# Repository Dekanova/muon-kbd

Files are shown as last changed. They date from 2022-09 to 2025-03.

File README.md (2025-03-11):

# A smol and simple osu keypad

This is the Muon PCB.

## Details
Firmware for this board can be found here https://github.com/Dekanova/muon-firmware.
ROM flash is pretty big and should be able to fit whatever you want on it.

Feel free to make a PR if you get other firmware working on this board!

### Features

- RP2040 (easy firmware changes)
- hybrid MX/low profile choc hotswap socket
- rgb keyglow & underglow
- usb-c

## Usage
TODO: once hybrid keyswitch gen is merged, move from local reference

- Kicad 6.0
- openinput library from kicad content&lib manager

## Images (last updated: v0.6)
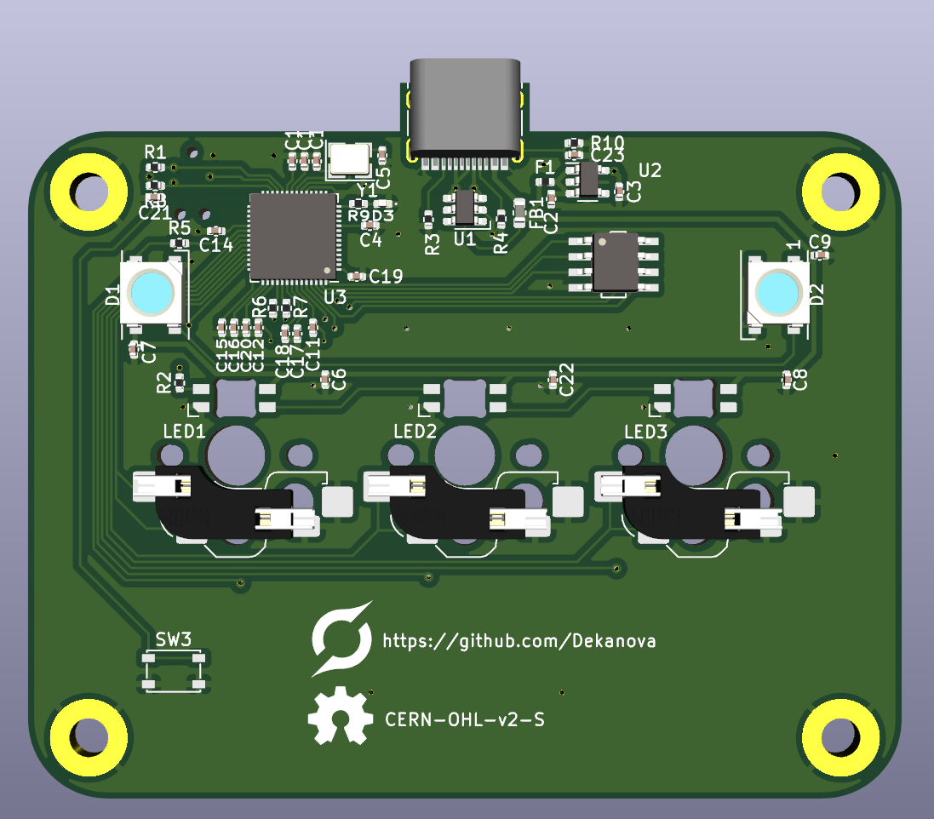
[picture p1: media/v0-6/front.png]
front Front

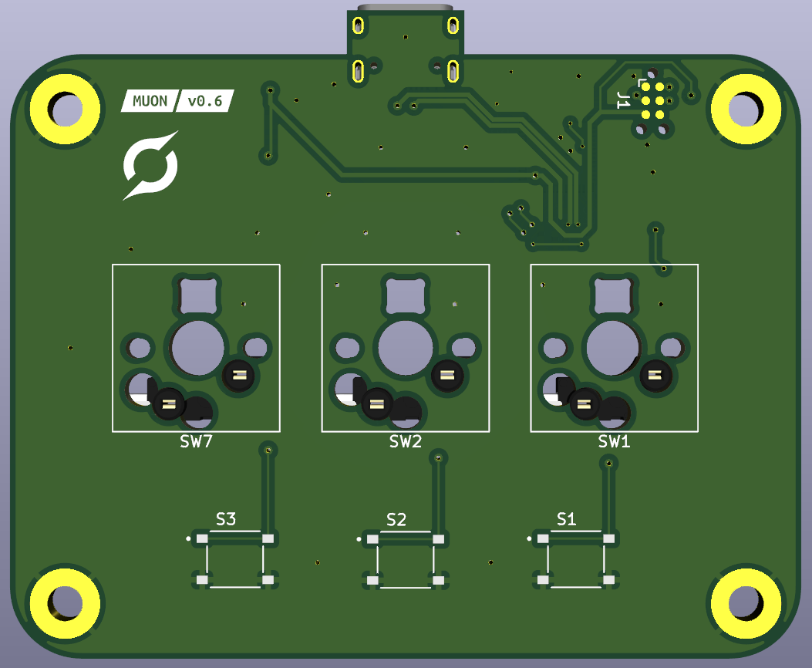
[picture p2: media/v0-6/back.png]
back Back


A huge thanks to openinput for their generic [KiCad lib](https://github.com/openinput-fw/openinput-kicad-library).

Also thanks to [marbastlib](https://github.com/ebastler/marbastlib) for their component lib.

This project is licenced under [CERN Open Hardware Licence v2 - Strongly Reciprocal](LICENCE) see [usage guide](LICENCE_USER_GUIDE) for more info

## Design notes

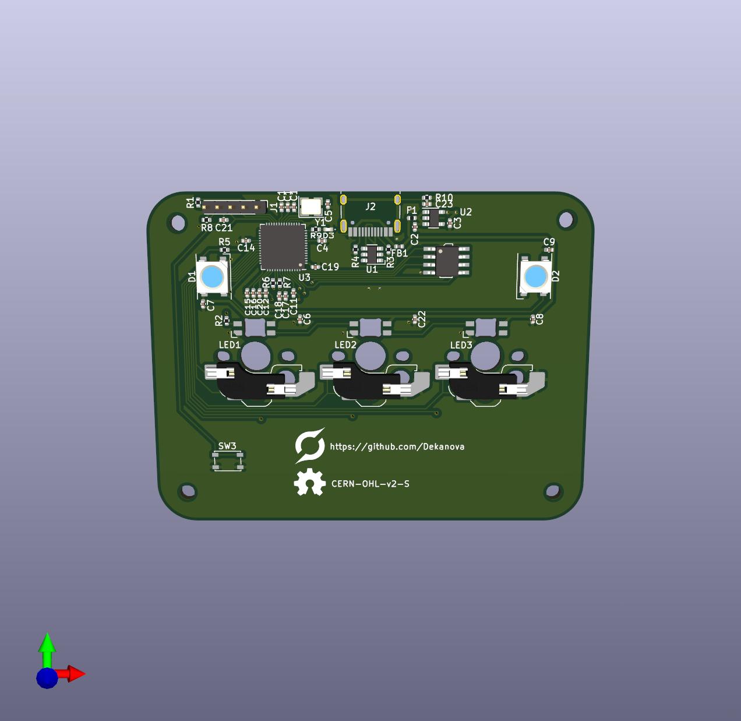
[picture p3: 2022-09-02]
media/v0-4/front.jpg

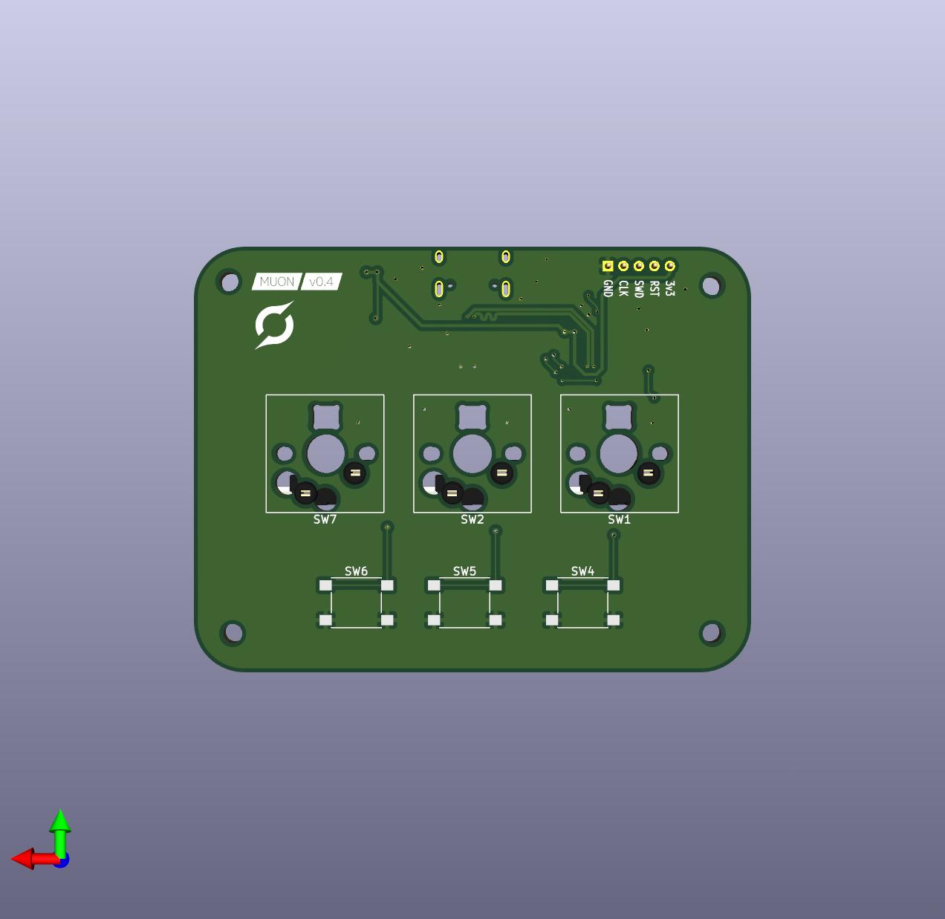
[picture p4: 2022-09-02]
media/v0-4/back.jpg

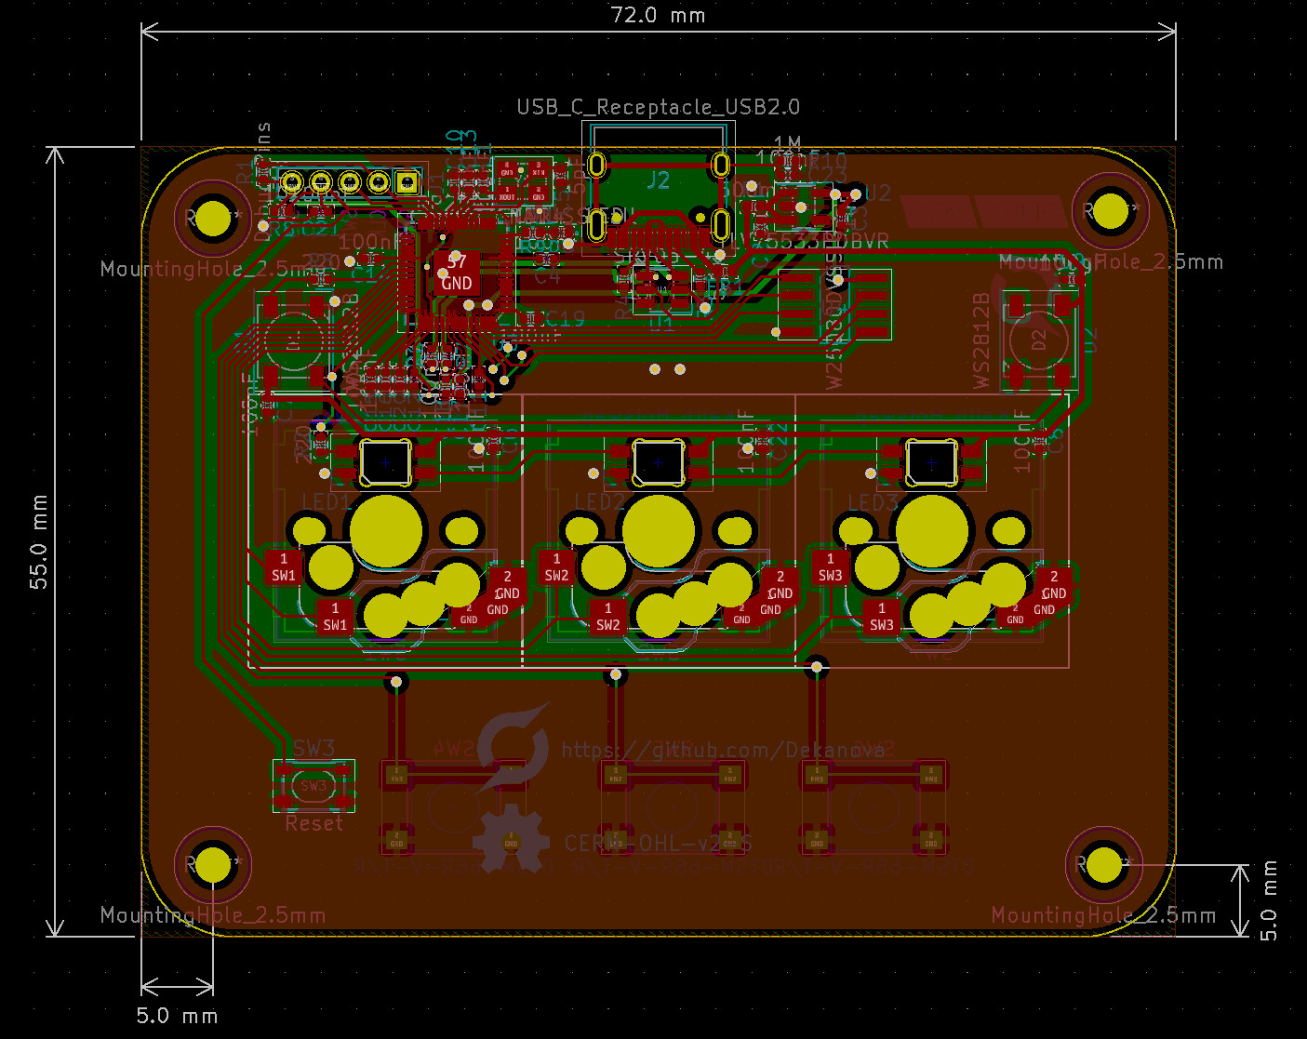
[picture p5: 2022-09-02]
media/v0-4/pcb.jpg

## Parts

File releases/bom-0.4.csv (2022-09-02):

Id | Designator | Package | Quantity | Designation | Supplier and ref
1 | R10 | R_0402_1005Metric | 1 | 1MΩ
2 | C23,C16,C17,C14,C13,C18,C21,C6,C11,C4,C15,C7,C10,C19,C8,C9,C22 | C_0402_1005Metric | 17 | 100nF
3 | F1 | Fuse_0402_1005Metric | 1 | 500mA
4 | R3,R4 | R_0402_1005Metric | 2 | 5.1k
5 | C1,C5 | C_0402_1005Metric | 2 | 5pF
6 | LED2,LED1,LED3 | LED_6028R | 3 | SK6812MINI-E
7 | R7,R6 | R_0402_1005Metric | 2 | 27Ω
8 | D2,D1 | LED_WS2812B_PLCC4_5.0x5.0mm_P3.2mm | 2 | WS2812B
9 | J2 | USB_C_Receptacle_HRO_TYPE-C-31-M-12 | 1 | USB_C_Receptacle_USB2.0
10 | D3 | LED_0402_1005Metric | 1 | STATUS LED
11 | U2 | SOT-23-5 | 1 | TLV75533PDBVR
12 | C12,C2,C20,C3 | C_0402_1005Metric | 4 | 1uF
13 | U4 | W25Q_SOIC-8 | 1 | W25Q80DVSSIG
14 | R9,R8 | R_0402_1005Metric | 2 | 10k
15 | SW3 | SW_SPST_PTS810 | 1 | Reset
16 | FB1 | L_0402_1005Metric | 1 | ~
17 | R1 | R_0402_1005Metric | 1 | 1k
18 | J1 | PinHeader_1x05_P2.00mm_Vertical | 1 | Debug Pins
19 | Y1 | Crystal_SMD_3225-4Pin_3.2x2.5mm | 1 | Crystal_GND24_Small
20 | R2,R5 | R_0402_1005Metric | 2 | 220Ω
21 | U3 | QFN-56-1EP_7x7mm_P0.4mm_EP3.2x3.2mm | 1 | RP2040
22 | U1 | SOT-23-6-routable | 1 | SRV05-4
23 | SW2,SW7,SW1 | SW_Hotswap_Kailh_MX_1.00u | 3 | Kailh Hotswap
24 | SW6,SW4,SW5 | SW_Push_1P1T_NO_6x6mm_H9.5mm | 3 | DTSM-66R-V-T/R

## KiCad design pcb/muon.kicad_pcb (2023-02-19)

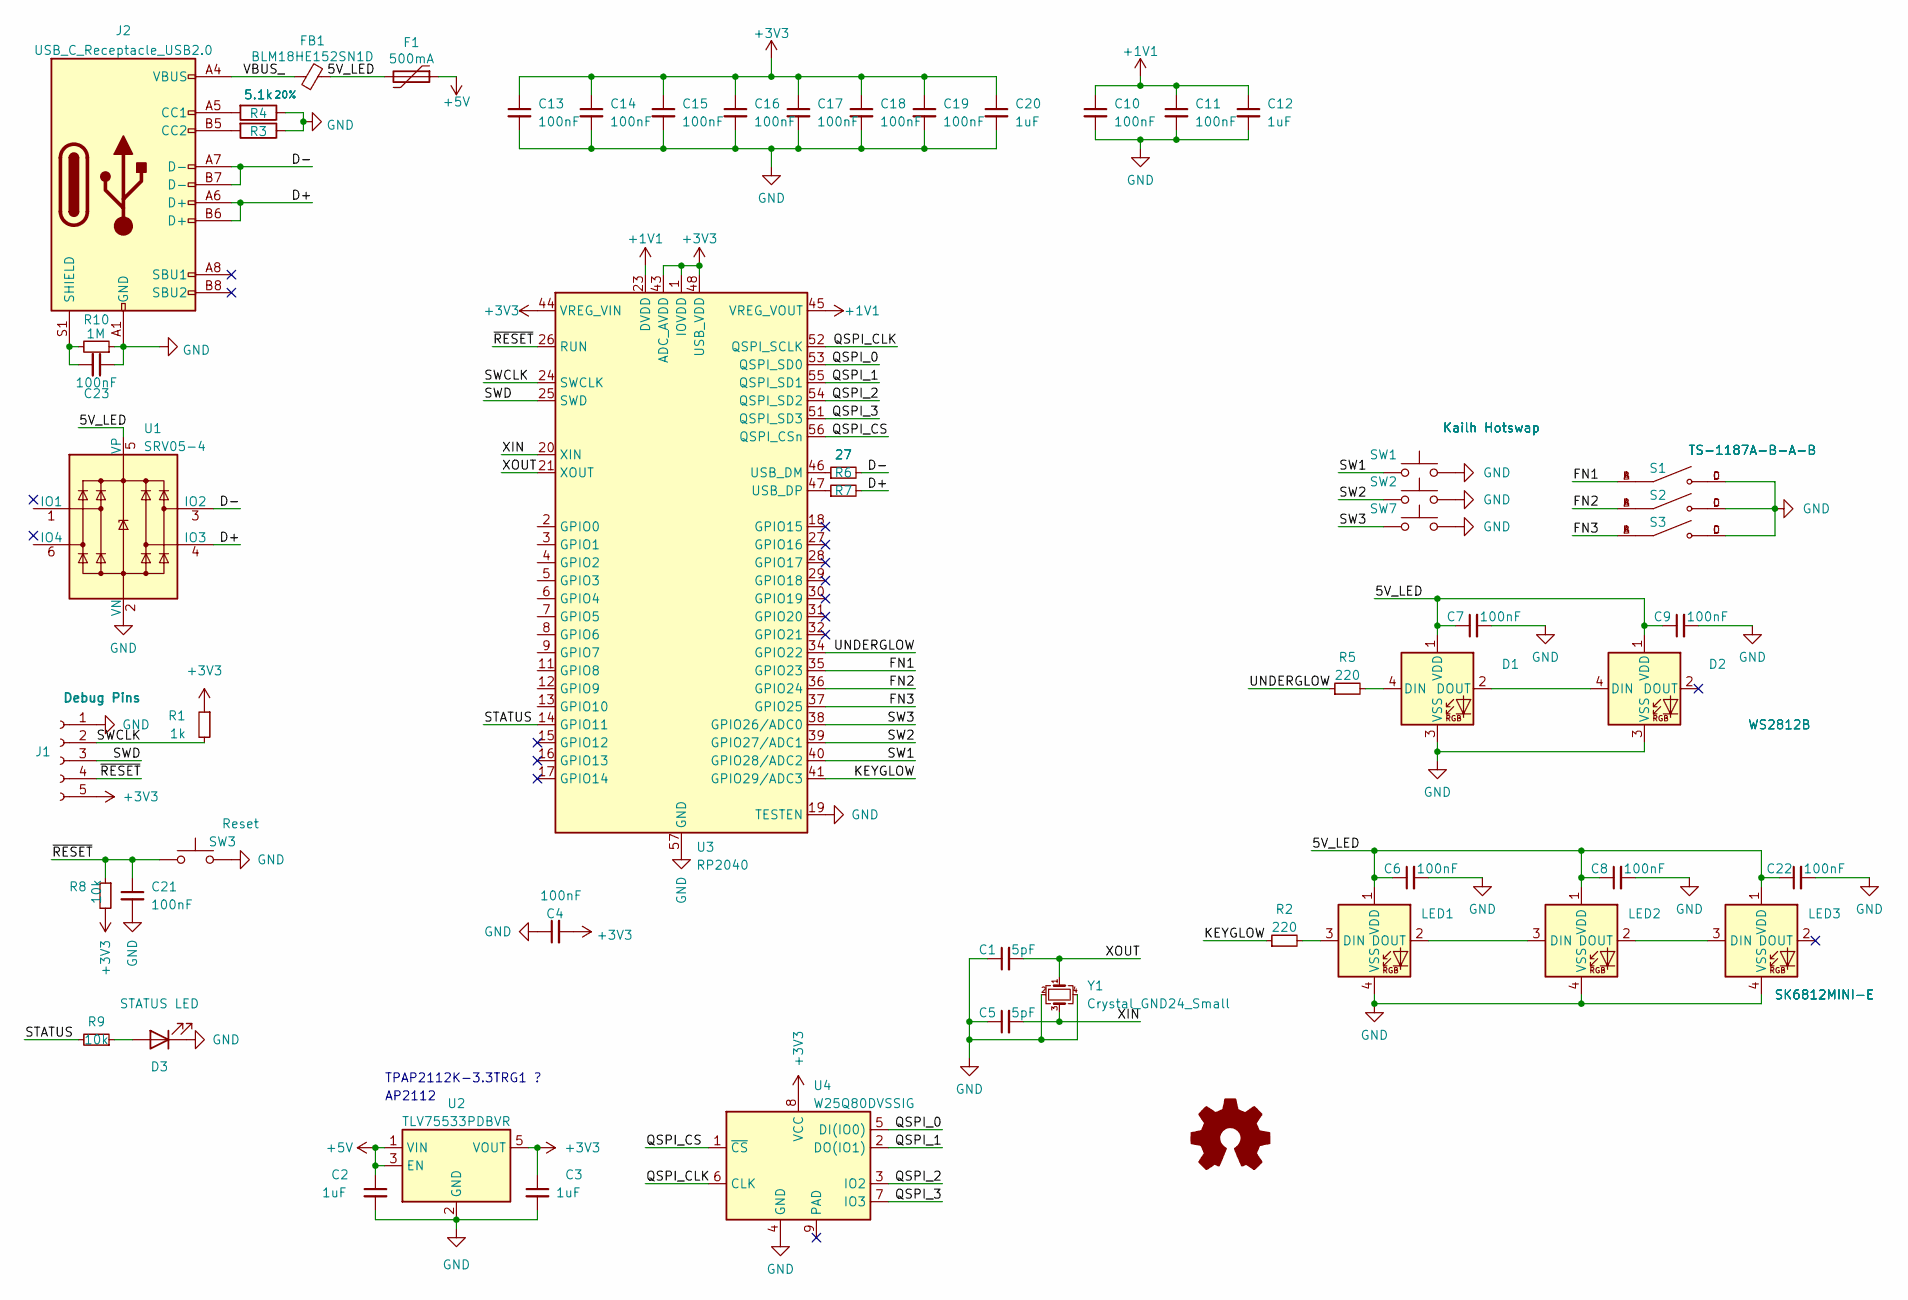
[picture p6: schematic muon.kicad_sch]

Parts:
C1, C5: 5pF; C_0402_1005Metric
C2, C3, C12, C20: 1uF; C_0402_1005Metric
C4, C6, C7, C8, C9, C10, C11, C13, C14, C15, C16, C17, C18, C19, C21, C22, C23: 100nF; C_0402_1005Metric
D1, D2: WS2812B; LED_WS2812B_PLCC4_5.0x5.0mm_P3.2mm
D3: STATUS LED; LED_0402_1005Metric
F1: 500mA; Fuse_0402_1005Metric
FB1: BLM18HE152SN1D; L_0603_1608Metric
J1: Debug Pins; Tag-Connect_TC2030-IDC-NL_2x03_P1.27mm_Vertical
J2: USB_C_Receptacle_USB2.0; USB_C_Receptacle_HRO_TYPE-C-31-M-12
LED1, LED2, LED3: SK6812MINI-E; LED_6028R
R1: 1k; R_0402_1005Metric
R2, R5: 220; R_0402_1005Metric
R3, R4: 5.1k; R_0402_1005Metric; Tolerance 20%
R6, R7: 27; R_0402_1005Metric
R8, R9: 10k; R_0402_1005Metric
R10: 1M; R_0402_1005Metric
S1, S2, S3: TS-1187A-B-A-B; SW_TS-1187A-B-A-B; PARTREV A0
SW1, SW2, SW7: Kailh Hotswap; SW_Hotswap_Hybrid_1.00u
SW3: Reset; SW_SPST_PTS810
U1: SRV05-4; SOT-23-6-routable
U2: TLV75533PDBVR; SOT-23-5
U3: RP2040; QFN-56-1EP_7x7mm_P0.4mm_EP3.2x3.2mm
U4: W25Q80DVSSIG; W25Q_SOIC-8
Y1: Crystal_GND24_Small; Crystal_SMD_3225-4Pin_3.2x2.5mm

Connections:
+1V1: C10.1, C11.1, C12.1, U3.23 (DVDD), U3.45 (VREG_VOUT), U3.50 (DVDD)
+3V3: C3.1, C4.2, C13.1, C14.1, C15.1, C16.1, C17.1, C18.1, C19.1, C20.1, J1.5, R1.1, R8.2, U2.5 (VOUT), U3.1 (IOVDD), U3.10 (IOVDD), U3.22 (IOVDD), U3.33 (IOVDD), U3.42 (IOVDD), U3.43 (ADC_AVDD), U3.44 (VREG_VIN), U3.48 (USB_VDD), U3.49 (IOVDD), U4.8 (VCC)
+5V: C2.1, F1.1, U2.1 (VIN), U2.3 (EN)
/5V_LED: C6.1, C7.1, C8.1, C9.1, C22.1, D1.1 (VDD), D2.1 (VDD), F1.2, FB1.2, LED1.1 (VDD), LED2.1 (VDD), LED3.1 (VDD), U1.5 (VP)
/D+: J2.A6 (D+), J2.B6 (D+), R7.2, U1.4 (IO3)
/D-: J2.A7 (D-), J2.B7 (D-), R6.2, U1.3 (IO2)
/FN1: S1.A, S1.B, U3.35 (GPIO23)
/FN2: S2.A, S2.B, U3.36 (GPIO24)
/FN3: S3.A, S3.B, U3.37 (GPIO25)
/KEYGLOW: R2.1, U3.41 (GPIO29/ADC3)
/QSPI_0: U3.53 (QSPI_SD0), U4.5 (DI(IO0))
/QSPI_1: U3.55 (QSPI_SD1), U4.2 (DO(IO1))
/QSPI_2: U3.54 (QSPI_SD2), U4.3 (IO2)
/QSPI_3: U3.51 (QSPI_SD3), U4.7 (IO3)
/QSPI_CLK: U3.52 (QSPI_SCLK), U4.6 (CLK)
/QSPI_CS: U3.56 (QSPI_CSn), U4.1 (~CS)
/STATUS: R9.2, U3.14 (GPIO11)
/SW1: SW1.1, U3.40 (GPIO28/ADC2)
/SW2: SW2.1, U3.39 (GPIO27/ADC1)
/SW3: SW7.1, U3.38 (GPIO26/ADC0)
/SWCLK: J1.2, R1.2, U3.24 (SWCLK)
/SWD: J1.3, U3.25 (SWD)
/UNDERGLOW: R5.1, U3.34 (GPIO22)
/VBUS_: FB1.1, J2.A4 (VBUS), J2.A9 (VBUS), J2.B4 (VBUS), J2.B9 (VBUS)
/XIN: C5.2, U3.20 (XIN), Y1.3
/XOUT: C1.2, U3.21 (XOUT), Y1.1
/~RESET: C21.1, J1.4, R8.1, SW3.1, U3.26 (RUN)
GND: C1.1, C2.2, C3.2, C4.1, C5.1, C6.2, C7.2, C8.2, C9.2, C10.2, C11.2, C12.2, C13.2, C14.2, C15.2, C16.2, C17.2, C18.2, C19.2, C20.2, C21.2, C22.2, C23.1, D1.3 (VSS), D2.3 (VSS), D3.1 (K), J1.1, J2.A1 (GND), J2.A12 (GND), J2.B1 (GND), J2.B12 (GND), LED1.4 (VSS), LED2.4 (VSS), LED3.4 (VSS), R3.1, R4.1, R10.1, S1.C, S1.D, S2.C, S2.D, S3.C, S3.D, SW1.2, SW2.2, SW3.2, SW7.2, U1.2 (VN), U2.2 (GND), U3.19 (TESTEN), U3.57 (GND), U4.4 (GND), Y1.2, Y1.4
unnamed: C23.2, J2.S1 (SHIELD), R10.2
unnamed: D1.2 (DOUT), D2.4 (DIN)
unnamed: D1.4 (DIN), R5.2
unnamed: D3.2 (A), R9.1
unnamed: J2.A5 (CC1), R4.2
unnamed: J2.B5 (CC2), R3.2
unnamed: LED1.2 (DOUT), LED2.3 (DIN)
unnamed: LED1.3 (DIN), R2.2
unnamed: LED2.2 (DOUT), LED3.3 (DIN)
unnamed: R6.1, U3.46 (USB_DM)
unnamed: R7.1, U3.47 (USB_DP)

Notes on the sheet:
AP2112
TPAP2112K-3.3TRG1 ?

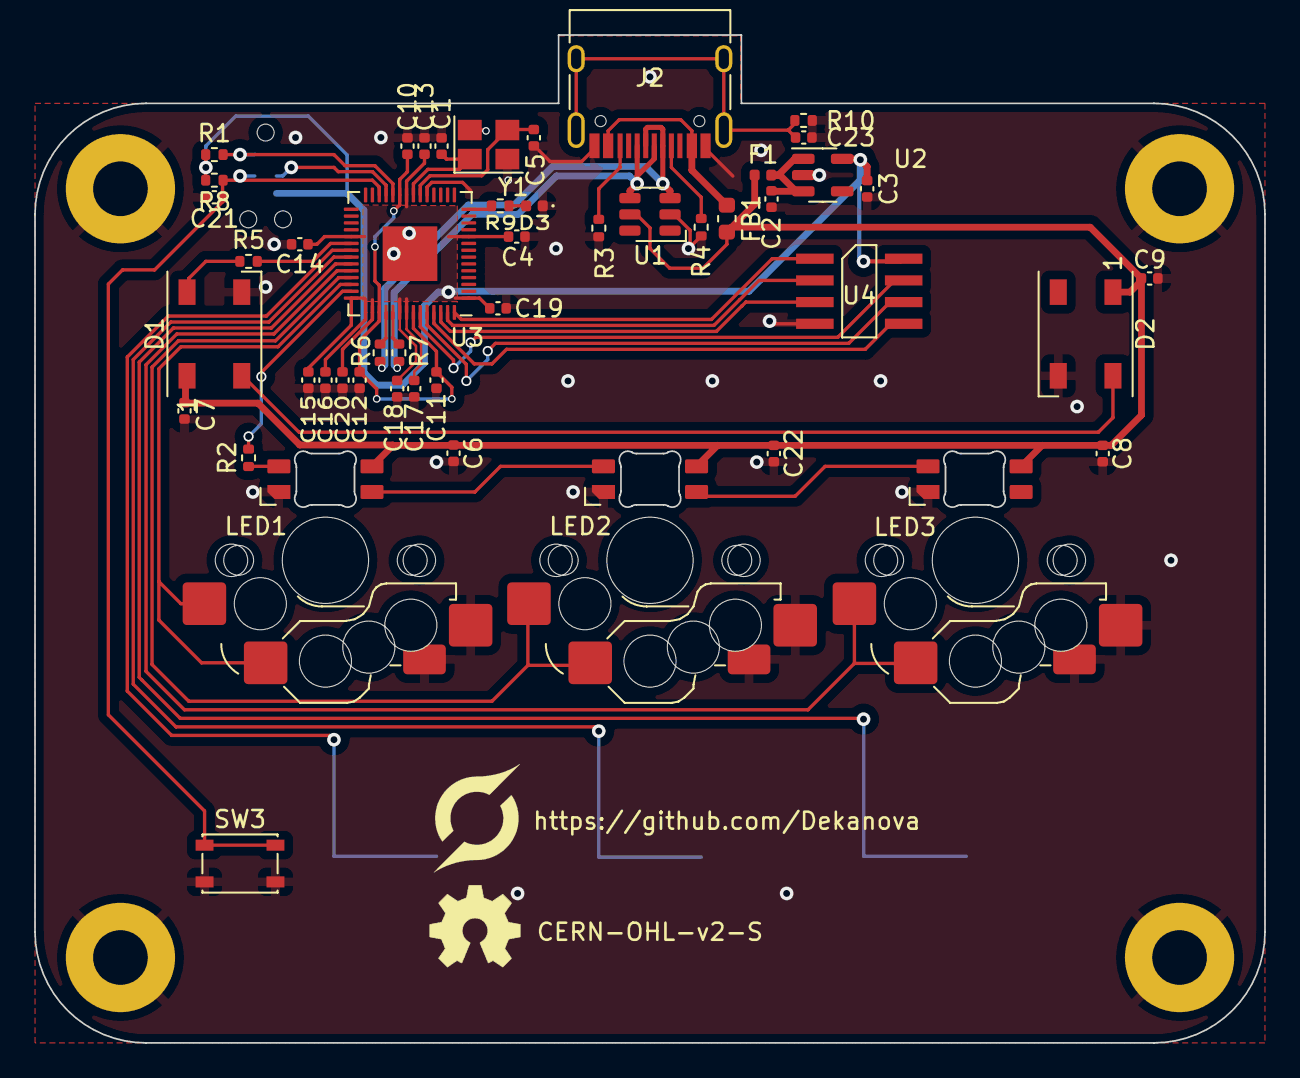
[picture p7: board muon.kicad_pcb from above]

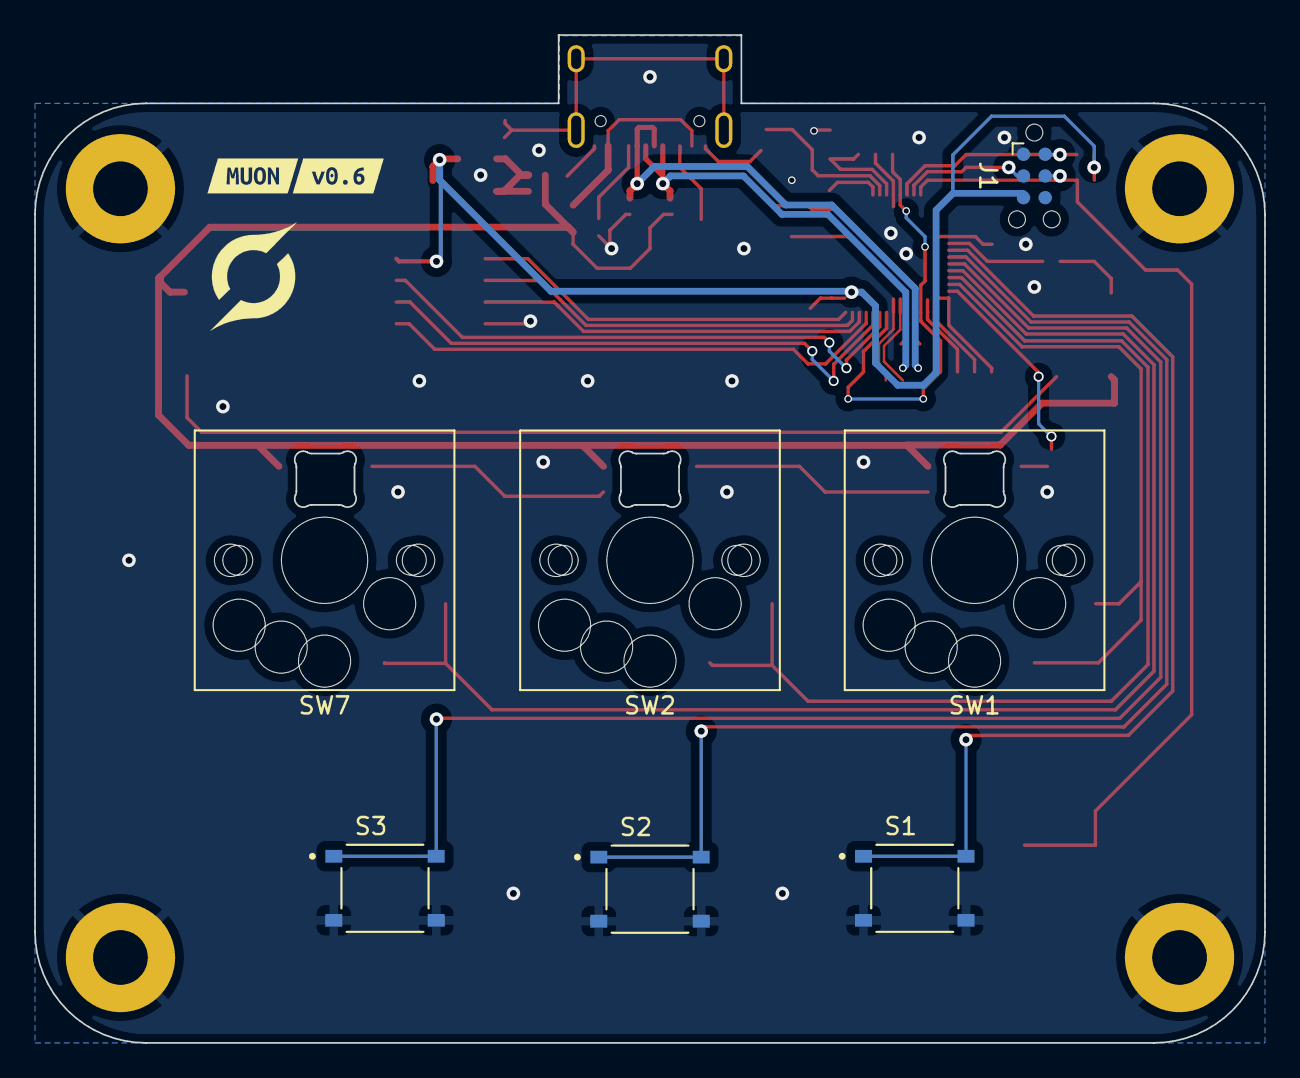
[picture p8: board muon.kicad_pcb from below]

Board: 2 copper layers, 72.0 x 59.0 mm, 57 parts (9 on the bottom side), 39 nets.

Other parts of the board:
kibuzzard-63718431: G***; kibuzzard-63718431
kibuzzard-63718440: G***; kibuzzard-63718440

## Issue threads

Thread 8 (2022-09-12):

Remove J1 from BOM

mriise, 2022-09-12:

mriise, 2022-11-14:
?? i need to write better issues...

Closed 2022-11-14.

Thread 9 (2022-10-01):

Fn buttons should be shorter (different part)

mriise, 2022-10-01:
we are only reaching up to the lower layer, so the switch plunger doesnt need to be 10mm long lol

mriise, 2022-11-14:
fixed by #10

Closed 2022-11-14.

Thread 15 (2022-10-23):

FInd a part number for Ferrite bead

mriise, 2022-10-23:
Ive been placing a 0ohm resistor in its place for dev boards but we should find an actual part that we can use and order.

Closed 2022-11-14.

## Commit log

2022-02-10 add the rest of the basic components
    [muon.kicad_pcb, muon.kicad_sch]
2022-02-10 re-route traces for pretty
    [muon.kicad_pcb, muon.kicad_sch]
2022-02-11 re-route again
    [muon.kicad_pcb, muon.kicad_sch]
2022-02-21 update schematic with proper parts
    [muon.kicad_pcb, muon.kicad_sch]
2022-03-13 re-route and remove 'uneeded' things
    [muon.kicad_pcb, muon.kicad_sch]
2022-05-30 add new PCB footprint lib
2022-05-31 lots of things
    [muon.kicad_pcb, muon.kicad_sch]
2022-05-31 close, but not quite v0.2
    [muon.kicad_pcb, muon.kicad_sch]
2022-06-08 add extra components for debugging and fix arragement of caps
    [muon.kicad_pcb, muon.kicad_sch]
2022-06-08 v0-2 'release' but not that release-ish
    [muon.kicad_pcb, muon.kicad_sch]
2022-06-26 minor fixes and shuffle
    [muon.kicad_pcb, muon.kicad_sch]
2022-07-01 all but 3 traces connected
    [muon.kicad_pcb, muon.kicad_sch]
2022-07-24 pre v0.3
    [muon.kicad_pcb, muon.kicad_sch]
2022-08-20 remove wireless, change LDO to more avaliable one, decouple USB shield
    [bom-0.4.csv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]
2022-09-02 revised v0.4, hybrid hotswap socket, fix off-center switches (off by .5mm)
    [muon-B_Cu.gbr, muon-B_Mask.gbr, muon-B_Paste.gbr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]
2022-10-15 Change USB port to be on opposite side
    [muon.kicad_pcb]
2022-10-15 Move USB closer to the edge of the case Add gitignore
    [muon.kicad_pcb]
2022-10-15 Change buttons and move them into place Update 3D models
    [muon.kicad_pcb, muon.kicad_sch]
2022-10-16 broad strokes
    [muon.kicad_pcb, muon.kicad_sch]
2022-10-17 usb back on main side
    [muon.kicad_pcb, muon.kicad_sch]
2022-10-23 final touches & export fab files
    [muon-B_Cu.gbr, muon-B_Mask.gbr, muon-B_Paste.gbr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]
2022-10-24 release v0.5
    [muon-B_Cu.gbr, muon-B_Mask.gbr, muon-B_Paste.gbr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]
2022-11-14 Pre-v0.6 - use TagConnect debug header - equally space underglow LEDs - add comment to replicate kibuzzard settings - use M3 mounting holes
    [muon.kicad_pcb, muon.kicad_sch]
2022-11-14 update page titles, use an actual Ferrite Bead (has just been a 0ohm resistor till now
    [muon.kicad_pcb, muon.kicad_sch]
2023-02-19 0.6 updates
    [muon-B_Cu.gbr, muon-B_Mask.gbr, muon-B_Paste.gbr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]

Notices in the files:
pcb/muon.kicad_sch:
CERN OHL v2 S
